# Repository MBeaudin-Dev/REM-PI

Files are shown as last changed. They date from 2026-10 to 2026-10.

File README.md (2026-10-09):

# REM-PI

Firmware for the Raspberry Pis used by Robot Event Manager. A Pi runs in one
of two roles, assigned by an admin when it is paired:

- **Kiosk**: shows a display page in full-screen Chromium.
- **Field node**: shows the field display *and* drives the relay HAT that
  enables, disables and switches the mode of the robots on its field.

This README covers how the relay HAT works. The code is in
[`pi_firmware/hardware.py`](pi_firmware/hardware.py).

## The relay HAT

The HAT has two relays, each driven by one GPIO pin on the Pi. Together they
reproduce the two control lines of the VEX V5 legacy Competition Port:

| Relay  | Physical pin | BCM GPIO | Controls |
| --- | --- | --- | --- |
| Enable | 11 | GPIO17 | Robots enabled or disabled |
| Mode | 29 | GPIO5 | Autonomous or driver (user) control |

The code uses `GPIO.BOARD` numbering, so the pins are referred to by their
physical header position (11 and 29), not their BCM numbers.

Setting a pin HIGH energizes its relay; setting it LOW de-energizes it.

## Robot states

The firmware only ever puts the HAT into one of three states:

| State | Enable pin (11) | Mode pin (29) | Method |
| --- | --- | --- | --- |
| **Disabled** | LOW (de-energized)  | LOW (de-energized)  | `disable()` |
| **Autonomous** | HIGH (energized) | LOW (de-energized)  | `enable_autonomous()` |
| **Driver** | HIGH (energized) | HIGH (energized) | `enable_driver()` |

With both relays de-energized the robots are disabled, so a crash, power loss
or unconfigured GPIO leaves the field in a safe state.

### Enable vs. disable

The **enable relay** decides whether robots may move at all.

- Enable pin **HIGH**: robots are **enabled**, in whichever mode the mode
  relay selects.
- Enable pin **LOW**: robots are **disabled**.

### Autonomous vs. driver

The **mode relay** decides which program the robots run while enabled.

- Mode pin **HIGH**: **driver (user) control**.
- Mode pin **LOW**: **autonomous**.

The mode pin only matters while the enable pin is HIGH. In the disabled state
the mode pin is left LOW.

## What triggers each state

The field node receives commands from the server over a WebSocket
([`pi_firmware/ws_client.py`](pi_firmware/ws_client.py)):

| Event | Result |
| --- | --- |
| `phase_change` with `phase: "autonomous"` | Autonomous |
| `phase_change` with `phase: "driver"` | Driver |
| `phase_change` with any other phase | Disabled |
| `estop` | Disabled |

The Pi also disables the robots on its own, without a command from the
server:

- **On startup**, as soon as the relay pins are set up.
- **If the server goes quiet** for 20 seconds (4 missed heartbeats), even if
  the connection still looks open.
- **If the connection to the server drops**, before each reconnect attempt.
- **On shutdown**, before releasing the GPIO pins.

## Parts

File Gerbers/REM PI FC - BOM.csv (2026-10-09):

Comment | Designator | Footprint
1N4007 | D1,D2 | Diode_THT:D_DO-41_SOD81_P10.16mm_Horizontal
KH-RJ45-56-8P8C-D | J2,J3,J4,J5 | Connector_RJ:RJ45_Amphenol_RJHSE538X
srd-05vdc-sl-c | K1-AD1,K2-Enable1 | Relay_THT:Relay_SPDT_SANYOU_SRD_Series_Form_C
PN2222A | Q1,Q2 | Package_TO_SOT_THT:TO-92
1206W4J0102T5E | R3,R4 | Resistor_SMD:R_1206_3216Metric
1206W4F300JT5E | R5,R6 | Resistor_SMD:R_1206_3216Metric

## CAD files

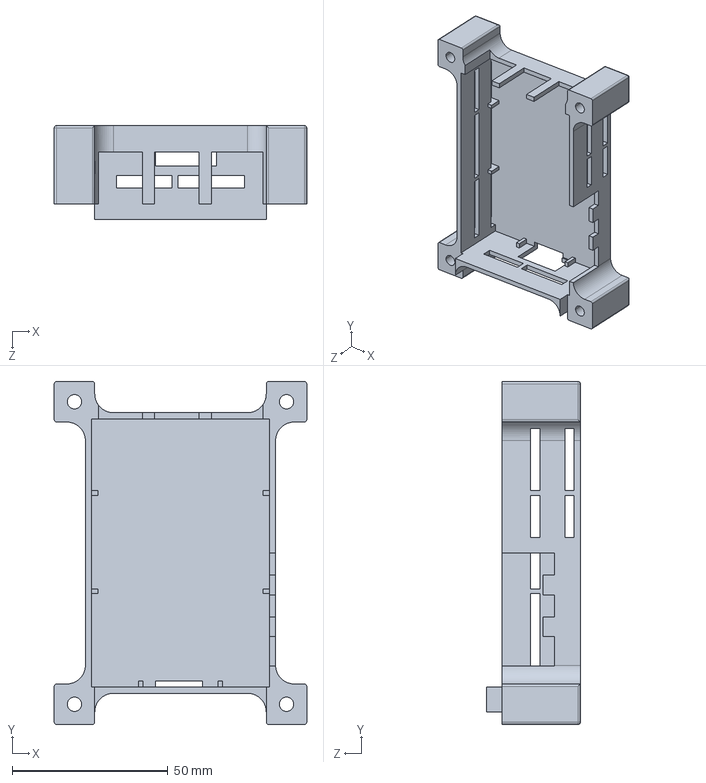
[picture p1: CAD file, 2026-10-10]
Cad Files/PI_REM_BOTTOM_REVB.STEP
81.0 x 110.0 x 30.1 mm

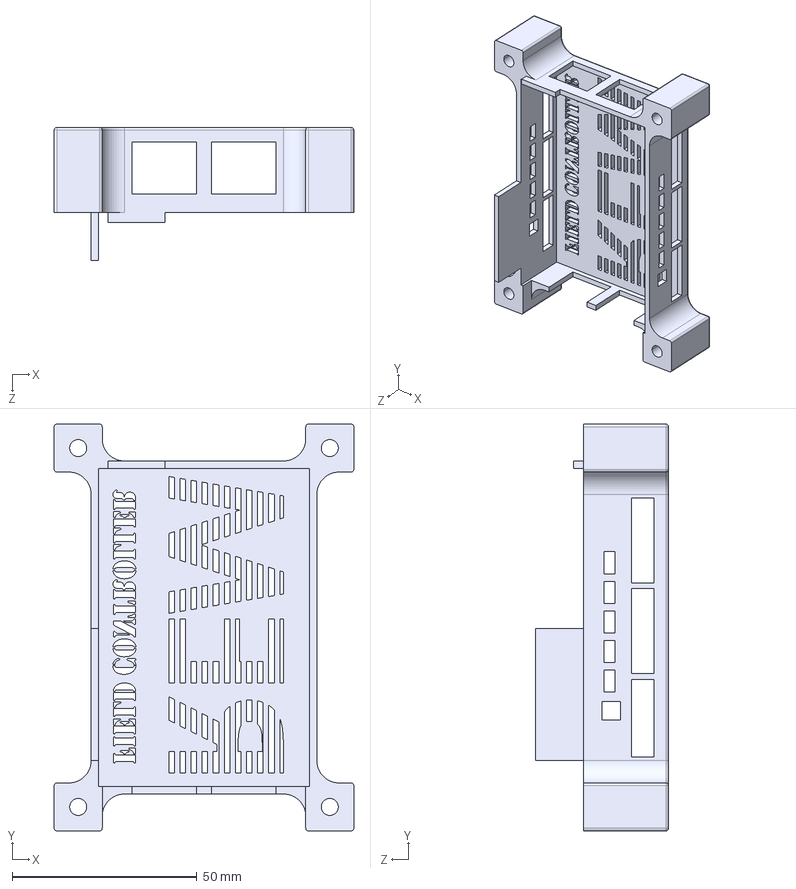
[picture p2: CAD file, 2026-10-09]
Cad Files/PI_REM_TOP_REVB.STEP
81.0 x 110.0 x 36.0 mm

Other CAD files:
Cad Files/PI_REM_BOTTOM_REVB.SLDPRT
Cad Files/PI_REM_TOP_REVB.SLDPRT

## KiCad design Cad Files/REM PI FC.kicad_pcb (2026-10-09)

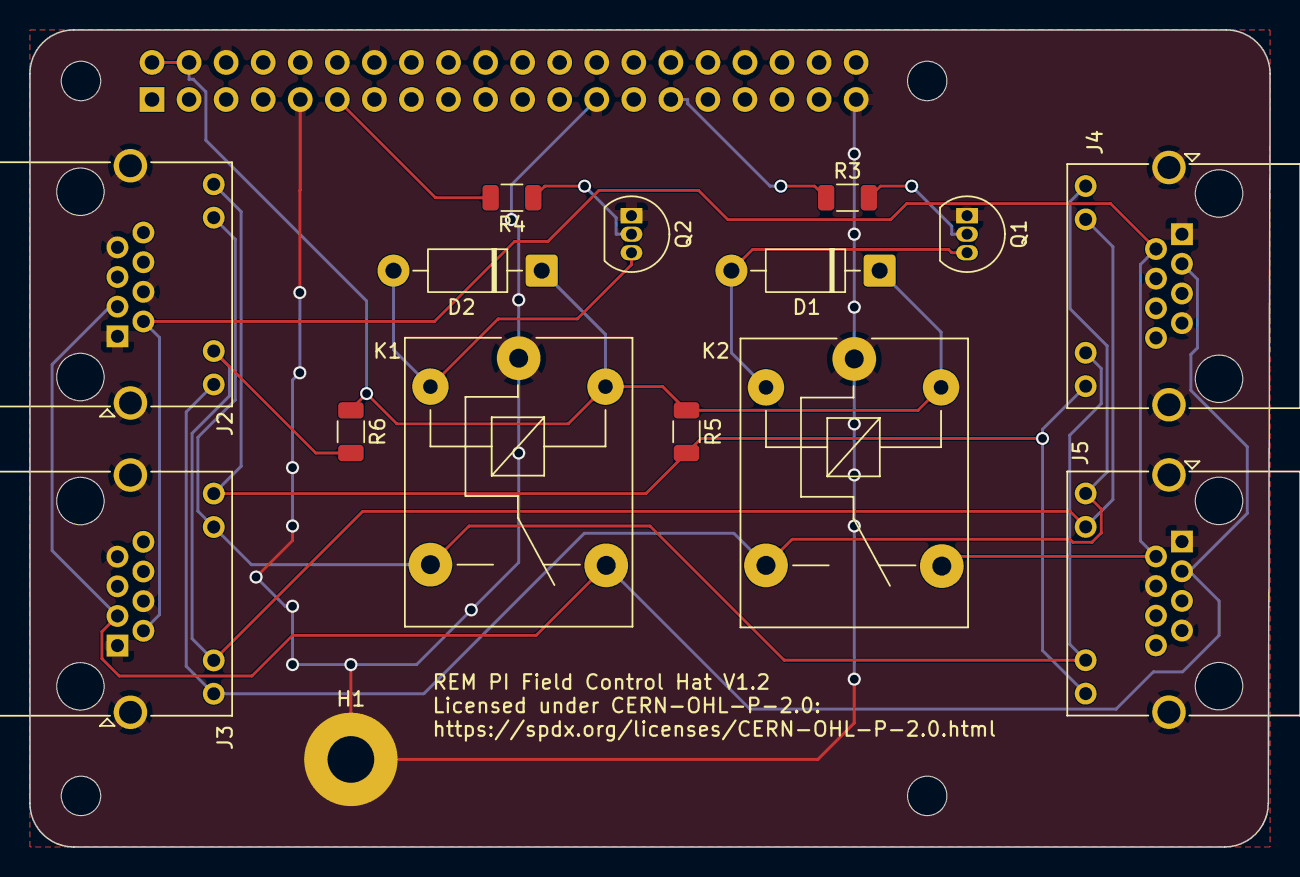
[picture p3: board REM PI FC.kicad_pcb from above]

Board: 2 copper layers, 85.0 x 56.0 mm, 20 parts (1 on the bottom side), 15 nets.

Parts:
D1, D2: 1N4007; D_DO-41_SOD81_P10.16mm_Horizontal
H1: MountingHole_Pad; MountingHole_3.2mm_M3_Pad
J1: GPIO; PinSocket_2x20_P2.54mm_Vertical
J2, J3, J4, J5: RJ45_LED_Shielded; RJ45_Amphenol_RJHSE538X
K1-AD1, K2-Enable1: Songle SRD-5VDC-SL-C; Relay_SPDT_SANYOU_SRD_Series_Form_C
MH1, MH2, MH3, MH4: MountingHole_2.7mm_M2.5
Q1, Q2: PN2222A; TO-92_Inline
R3, R4: R1k; R_1206_3216Metric
R5, R6: R30; R_1206_3216Metric

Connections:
+3V3: J1.1, J1.17
+5V: D1.1 (K), D2.1 (K), J1.2, J1.4, K1-AD1.5, K2-Enable1.5, R5.1, R6.1
/GPIO5: J1.29, R3.1
/GPIO17: J1.11, R4.2
GND: H1.1 (1_1), J1.6, J1.9, J1.14, J1.20, J1.25, J1.30, J1.34, J1.39, J2.1, J2.4, J2.7, J2.SH, J3.1, J3.4, J3.7, J3.SH, J4.1, J4.4, J4.7, J4.SH, J5.1, J5.4, J5.7, J5.SH, K1-AD1.1, K2-Enable1.1, Q1.1 (E), Q2.1 (E)
unnamed: D1.2 (A), K1-AD1.2, Q1.3 (C)
unnamed: D2.2 (A), K2-Enable1.2, Q2.3 (C)
unnamed: J2.2, J3.2, J4.2, J5.2, K1-AD1.4
unnamed: J2.3, J3.3, J4.3, J5.3, K2-Enable1.4
unnamed: J2.9, J3.9, J4.9, J5.9, K1-AD1.3
unnamed: J2.10, J3.10, J4.10, J5.10, R6.2
unnamed: J2.11, J3.11, J4.11, J5.11, K2-Enable1.3
unnamed: J2.12, J3.12, J4.12, J5.12, R5.2
unnamed: Q1.2 (B), R3.2
unnamed: Q2.2 (B), R4.1

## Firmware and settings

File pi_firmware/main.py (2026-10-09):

#!/usr/bin/env python3
"""Entry point for the field-node/kiosk Pi service.

The role is assigned by an admin at pairing time:
  - "kiosk"      -- Chromium at {server}/kiosk.html.
  - "field_node" -- Chromium at {server}/field-display.html plus relay control
                    (ws_client.FieldNodeClient).

the Pi advertises itself over mDNS and waits for the server to
push credentials (claim_listener.py). Fallback: --server URL --pair CODE.
"""

import argparse
import asyncio
import sys
import threading
import time
import urllib.error
import urllib.request

import claim_listener
import hardware
import kiosk
import pairing
from ws_client import FieldNodeClient, ServerUnreachable

#The kiosk role has no WebSocket to notice a dead server, so it polls.
KIOSK_PROBE_INTERVAL_SECONDS = 5
KIOSK_GIVE_UP_AFTER_SECONDS = 60


def _device_session_fragment(cookie):
    """Turns "rem_session=device:<id>:<token>" into a URL fragment that
    static/auth.js exchanges for a browser cookie. A fragment is never sent
    to the server, so the token stays out of access logs. Returns "" if the
    cookie isn't in that shape."""
    try:
        # "rem_session=device:<id>:<token>" -> ["device", "<id>", "<token>"]
        _, device_id, token = cookie.split("=", 1)[1].split(":", 2)
    except (IndexError, ValueError):
        return ""
    return "#device-session={}:{}".format(device_id, token)


def _kiosk_session_status(server_url, cookie):
    """Returns "ok", "revoked" (401/403) or "unreachable"."""
    request = urllib.request.Request(
        server_url.rstrip("/") + "/api/devices/me", headers={"Cookie": cookie}
    )
    try:
        with urllib.request.urlopen(request, timeout=5):
            return "ok"
    except urllib.error.HTTPError as e:
        if e.code in (401, 403):
            return "revoked"
        # Any other HTTP error still means the server answered.
        return "ok"
    except Exception:
        return "unreachable"


def parse_args(argv):
    parser = argparse.ArgumentParser(description="Robot Event Manager field-node/kiosk service")
    parser.add_argument(
        "--server",
        help="Server base URL, e.g. http://192.168.1.50:8000 -- only needed with --pair",
    )
    parser.add_argument(
        "--pair",
        metavar="CODE",
        help="Pairing code fallback for networks where mDNS discovery doesn't work",
    )
    parser.add_argument(
        "--pair-only", action="store_true", help="Pair (or wait to be claimed) and exit, without launching anything"
    )
    parser.add_argument(
        "--no-kiosk", action="store_true", help="Don't launch Chromium -- for headless dev/testing"
    )
    return parser.parse_args(argv)


def _wait_to_be_discovered(launch_kiosk):
    hostname = kiosk.local_hostname()
    ip_address = kiosk.local_ip()
    print(
        "Not yet paired. Broadcasting as '{}' ({}) -- waiting for an admin to pair it "
        "from the Devices tab's 'Discovered Field Devices' list.".format(hostname, ip_address)
    )

    # Show the hostname/IP on screen so an operator can match this Pi to the
    # admin's Discovered Field Devices list.
    waiting_chromium = None
    if launch_kiosk:
        waiting_chromium = kiosk.Chromium()
        waiting_chromium.show("file://" + kiosk.write_waiting_page(hostname, ip_address))

    try:
        # Blocks until the server pushes this Pi's credentials.
        server_url, device_id, session_token, role, name = claim_listener.wait_for_claim()
    finally:
        if waiting_chromium is not None:
            waiting_chromium.stop()

    # Same cookie format the server issues on the pairing-code path.
    cookie = "rem_session=device:{}:{}".format(device_id, session_token)
    pairing.save_session(server_url, cookie, role, name)
    print("Claimed as device {} ({}, role={})".format(device_id, name, role))
    return server_url, cookie, role, name


def _run_field_node(server_url, cookie, name, launch_kiosk):
    # Relays are set to disabled as soon as this is created.
    hw = hardware.RelayHardware()
    chromium = kiosk.Chromium() if launch_kiosk else None
    if chromium is not None:
        chromium.show(
            server_url.rstrip("/") + "/field-display.html" + _device_session_fragment(cookie)
        )
        # Waits for X to come up, so keep it off the main thread.
        threading.Thread(
            target=kiosk.detect_and_report_ui_scale, args=(server_url, cookie), daemon=True
        ).start()
    client = FieldNodeClient(server_url, cookie, name, hw)
    try:
        # Runs until the server has been unreachable for GIVE_UP_AFTER_SECONDS.
        asyncio.run(client.run())
    except ServerUnreachable as e:
        #server_url is probably stale, clearing the session makes the next
        #run fall back to auto-discovery.
        print("Giving up on", server_url, "--", e)
        pairing.clear_session()
    except KeyboardInterrupt:
        pass
    finally:
        # Always leave the robots disabled on the way out.
        hw.cleanup()
        if chromium is not None:
            chromium.stop()


def _run_kiosk(server_url, cookie, launch_kiosk):
    if not launch_kiosk:
        print("Paired as a Display Pi. Re-run without --no-kiosk to launch its Chromium display.")
        return
    chromium = kiosk.Chromium()
    chromium.show(server_url.rstrip("/") + "/kiosk.html" + _device_session_fragment(cookie))
    threading.Thread(
        target=kiosk.detect_and_report_ui_scale, args=(server_url, cookie), daemon=True
    ).start()
    unreachable_since = None
    try:
        # Check in with the server until Chromium exits or we give up.
        while chromium.poll() is None:
            status = _kiosk_session_status(server_url, cookie)
            if status == "revoked":
                print("This device's session was revoked or removed -- re-discovering")
                pairing.clear_session()
                break
            if status == "ok":
                unreachable_since = None
            else:
                # Start the give-up timer on the first failed check.
                unreachable_since = unreachable_since or time.monotonic()
                if time.monotonic() - unreachable_since > KIOSK_GIVE_UP_AFTER_SECONDS:
                    print(
                        "Giving up on", server_url,
                        "-- unreachable for over", KIOSK_GIVE_UP_AFTER_SECONDS, "s",
                    )
                    pairing.clear_session()
                    break
            time.sleep(KIOSK_PROBE_INTERVAL_SECONDS)
    except KeyboardInterrupt:
        pass
    finally:
        chromium.stop()


def main(argv=None):
    args = parse_args(argv if argv is not None else sys.argv[1:])
    launch_kiosk = not args.no_kiosk

    cached_url, cached_cookie, cached_role, cached_name = pairing.load_session()

    # Credentials come from, in order: an explicit --pair code, the saved
    # session, or waiting to be claimed over the network.
    try:
        if args.pair:
            server_url = args.server or cached_url
            if not server_url:
                print("No server URL given -- pass --server http://<host>:<port>", file=sys.stderr)
                return 1
            server_url, cookie, role, name = pairing.ensure_paired(server_url, args.pair)
        elif cached_cookie:
            server_url, cookie, role, name = cached_url, cached_cookie, cached_role, cached_name
        else:
            server_url, cookie, role, name = _wait_to_be_discovered(launch_kiosk)
    except RuntimeError as e:
        print("Pairing error:", e, file=sys.stderr)
        return 1
    except KeyboardInterrupt:
        return 1

    if args.pair_only:
        print("Paired successfully as '{}' (role={})".format(name, role))
        return 0

    if role == "field_node":
        _run_field_node(server_url, cookie, name, launch_kiosk)
    elif role == "kiosk":
        _run_kiosk(server_url, cookie, launch_kiosk)
    else:
        print("Paired with role '{}', which this firmware doesn't know how to run.".format(role), file=sys.stderr)
        return 1
    return 0


if __name__ == "__main__":
    sys.exit(main())

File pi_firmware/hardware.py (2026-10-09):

"""GPIO driver for the field-control relay board."""


class RelayHardware:
    """Drives the two-relay board: RELAY_ENABLE_PIN (enabled/disabled) and
    RELAY_MODE_PIN (autonomous/driver), matching the V5 legacy Competition
    Port's signal lines.

    HIGH energizes a relay. 
    
    Enable pin HIGH = enabled, LOW = disabled.
    MODE pin HIGH = Usercontrol, LOW = auto.

    `RPi.GPIO` here is provided by rpi-lgpio (see setup.sh), which also works
    on the Pi 5."""

    # Physical header pins (BOARD mode), not BCM numbers.
    RELAY_ENABLE_PIN = 11
    RELAY_MODE_PIN = 29

    def __init__(self):
        # Imported here so importing this module doesn't need a Pi.
        import RPi.GPIO as GPIO

        self._gpio = GPIO
        self._gpio.setmode(GPIO.BOARD)
        self._gpio.setup(self.RELAY_ENABLE_PIN, GPIO.OUT)
        self._gpio.setup(self.RELAY_MODE_PIN, GPIO.OUT)
        # Start in the safe state.
        self.disable()

    def enable_autonomous(self):
        self._gpio.output(self.RELAY_ENABLE_PIN, self._gpio.HIGH)
        self._gpio.output(self.RELAY_MODE_PIN, self._gpio.LOW)
        print("AUTO, RelayEnable ON, RelayMode OFF/AUTO")

    def enable_driver(self):
        self._gpio.output(self.RELAY_ENABLE_PIN, self._gpio.HIGH)
        self._gpio.output(self.RELAY_MODE_PIN, self._gpio.HIGH)
        print("USERCONTROL, RelayEnable ON, RelayMode ON/USERCONTROL")

    def disable(self):
        self._gpio.output(self.RELAY_ENABLE_PIN, self._gpio.LOW)
        self._gpio.output(self.RELAY_MODE_PIN, self._gpio.LOW)
        print("STOP, RelayEnable OFF And RelayMode OFF")

    def cleanup(self):
        self.disable()
        # Releases the pins. With HIGH = enabled, released pins leave the
        # relays de-energized, so the robots stay disabled.
        self._gpio.cleanup()

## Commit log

2026-10-09 Improved static resistance
    [REM PI FC.kicad_pcb, REM PI FC.kicad_sch]
2026-10-09 Fixed tolerances
    [PI_REM_BOTTOM_REVB.SLDPRT, PI_REM_BOTTOM_REVB.STEP, PI_REM_TOP_REVB.SLDPRT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]
2026-10-09 Deleted old files
    [PI_REM_BOTTOM_REVA.SLDPRT]
2026-10-09 Fixing files
    [PI_REM_BOTTOM_REVB.SLDPRT, PI_REM_BOTTOM_REVB.STEP, PI_REM_TOP_REVB.SLDPRT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]
2026-10-10 Added More Vents
    [PI_REM_BOTTOM_REVB.SLDPRT, PI_REM_BOTTOM_REVB.STEP]
2026-10-16 Hole revisions
2026-10-16 Delete Cad Files/PI_REM_BOTTOM_REVB.SLDPRT
    Old

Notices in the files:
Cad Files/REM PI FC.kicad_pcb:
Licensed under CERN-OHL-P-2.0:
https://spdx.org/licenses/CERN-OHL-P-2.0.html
